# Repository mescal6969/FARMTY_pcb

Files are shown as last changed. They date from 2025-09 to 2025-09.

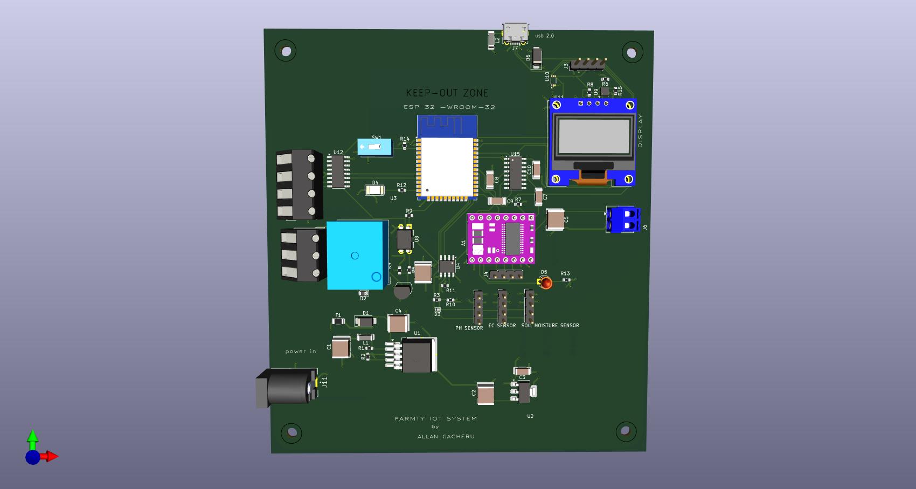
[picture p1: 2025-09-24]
farmty FULL.jpg

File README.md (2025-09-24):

 Farmty – IoT Smart Farming System

Farmty is an IoT-based smart farming system designed to monitor and control farm parameters in real time.  
This repository contains the KiCad PCB design , schematics , and related files for the Farmty hardware.

##  Features
- ESP32-WROOM-32 microcontroller (with WiFi + Bluetooth)
- RS485 sensor support:
  - Soil moisture
  - pH sensor
  - EC (Electrical Conductivity)
  - Temperature
- BME280 (humidity, pressure, temperature sensor)
- Load cell integration (for smart weighing)
- OLED (SSD1306) display
- Stepper motor driver
- Relay control for automation
- PC817 optocoupler isolation
- USB-to-UART via CH340C
- Modular power supply and terminal blocks

---

##  Software
- **Firmware:** ESP-IDF / Arduino framework
- **Programming language:** Python (for data processing) + C++ (for microcontroller)
- **IoT Dashboard:** Cloud-ready, customizable with MQTT/HTTP

---

##  Hardware
- Designed in KiCad
- Includes hierarchical schematics for modularity
- PCB fabrication-ready

##  How to Use
1. Clone this repo:
   ```bash
   https://github.com/mescal6969/FARMTY_pcb
2. Open the project in KiCad.
3. Modify schematics/PCB as needed.
4. Generate Gerber files for manufacturing.
5.Flash ESP32 with firmware to connect to IoT dashboard.

## IoT Integration

Farmty uses the **ESP32 WiFi module** to connect to the cloud.  
It can be integrated with:  
- **Blynk**  
- **ThingsBoard**  
- **Node-RED**  
- **MQTT brokers** (Mosquitto, HiveMQ)  

## License

This project is open-source under the **MIT License**.  
Feel free to use, modify, and share with attribution.

 Author
Allan Ng’ang’a Gacheru
BSc Mechatronics Engineering
Dedan Kimathi University of Technology

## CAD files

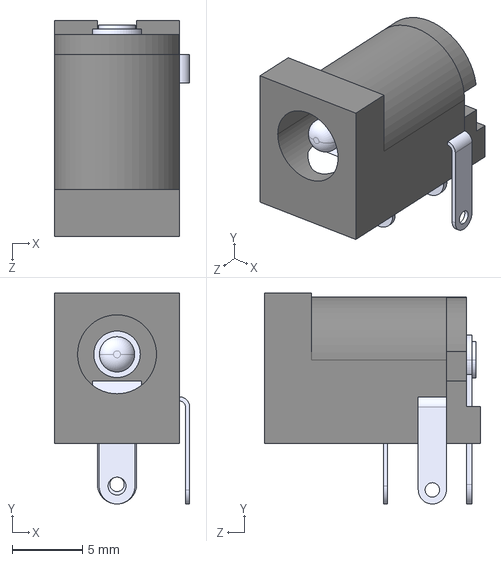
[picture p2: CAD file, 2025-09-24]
EJ508B.step
9.60 x 15.0 x 15.4 mm

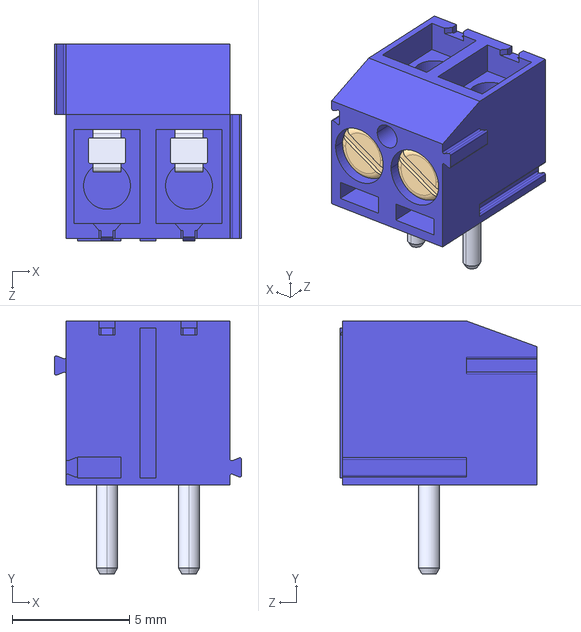
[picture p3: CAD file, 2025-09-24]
OSTTF020161--3DModel-STEP-56544.STEP
8.00 x 10.8 x 8.40 mm

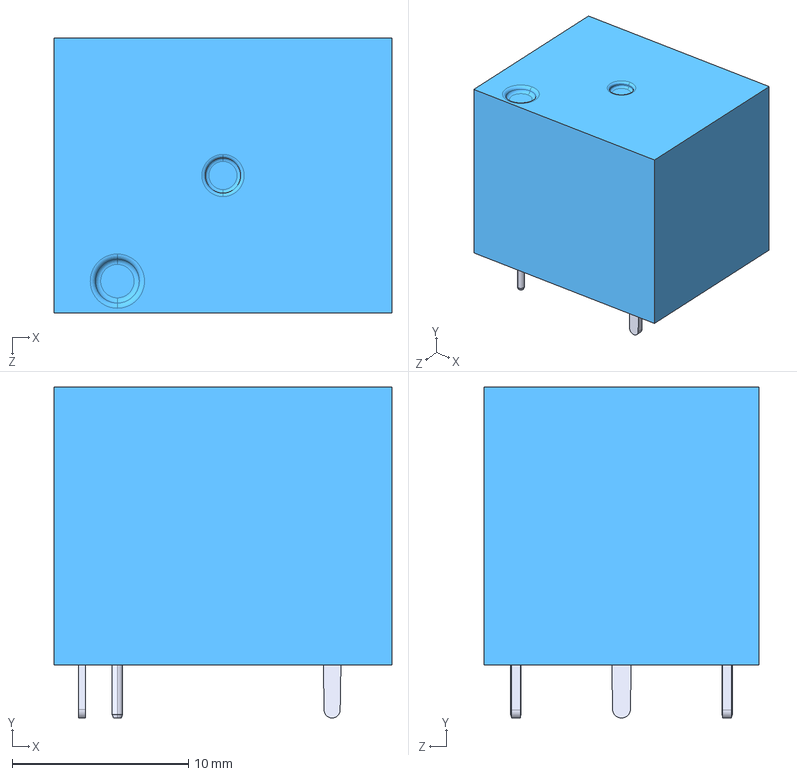
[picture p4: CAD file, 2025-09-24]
SRD-12VDC-SL-C.STEP
19.2 x 18.8 x 15.6 mm

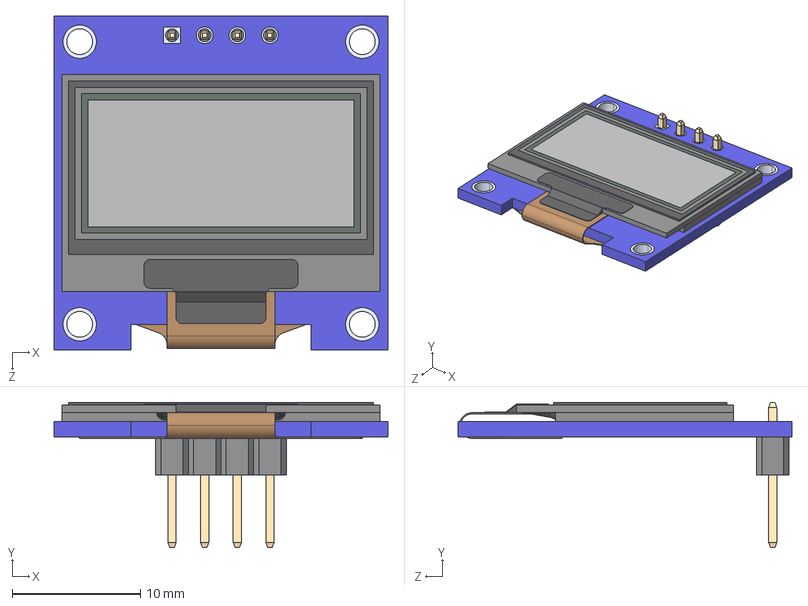
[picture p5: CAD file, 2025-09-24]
DM-OLED096-636--3DModel-STEP-56544.STEP
26.0 x 11.3 x 26.0 mm
DM-OLED096-636_Module
DM-OLED096-636_Panel

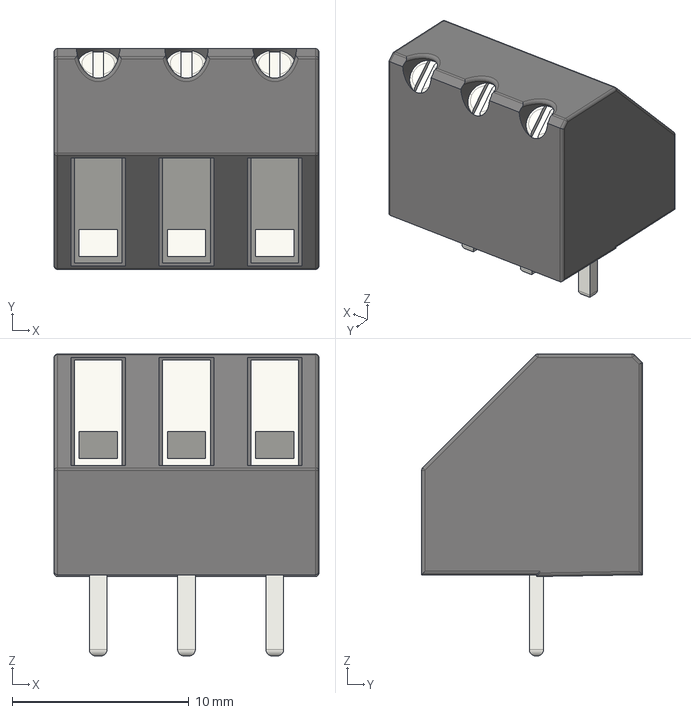
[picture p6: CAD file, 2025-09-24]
Altech_AK300_1x03_P5.00mm_45-Degree.step
15.0 x 12.5 x 17.1 mm

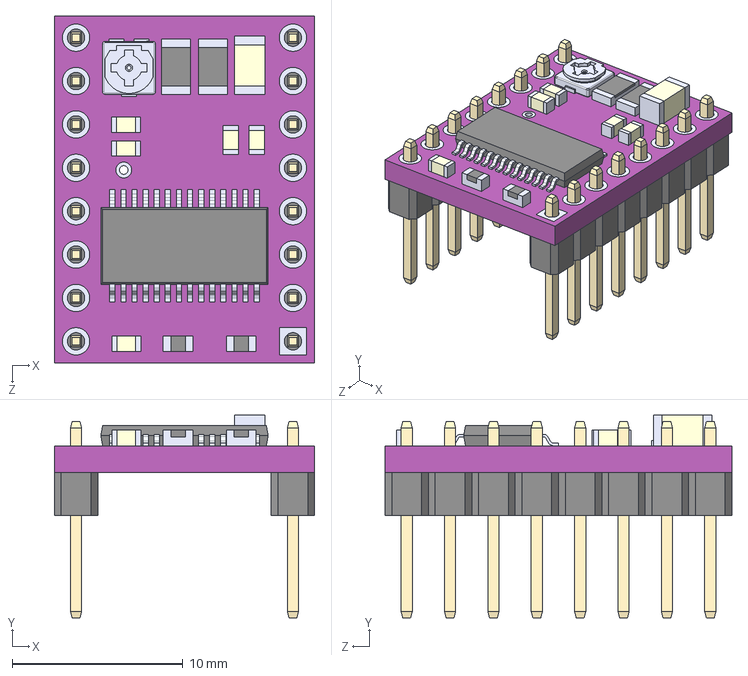
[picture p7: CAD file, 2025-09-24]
DRV8825 STEPPER MOTOR DRIVER CARRIER--3DModel-STEP-1.STEP
15.2 x 11.9 x 20.3 mm

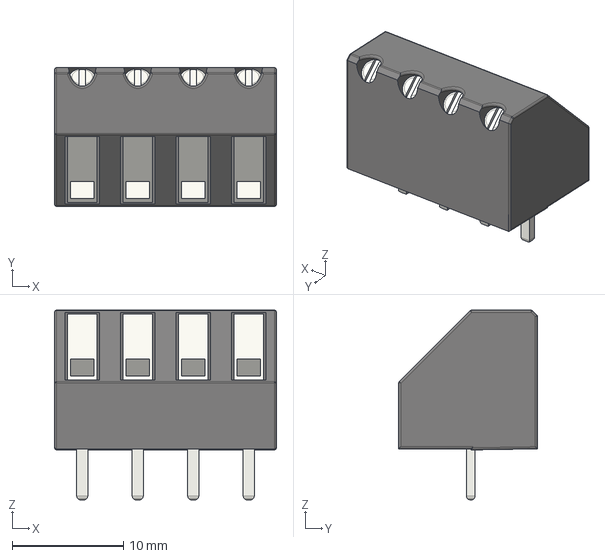
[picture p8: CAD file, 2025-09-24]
Altech_AK300_1x04_P5.00mm_45-Degree.step
20.0 x 12.5 x 17.1 mm

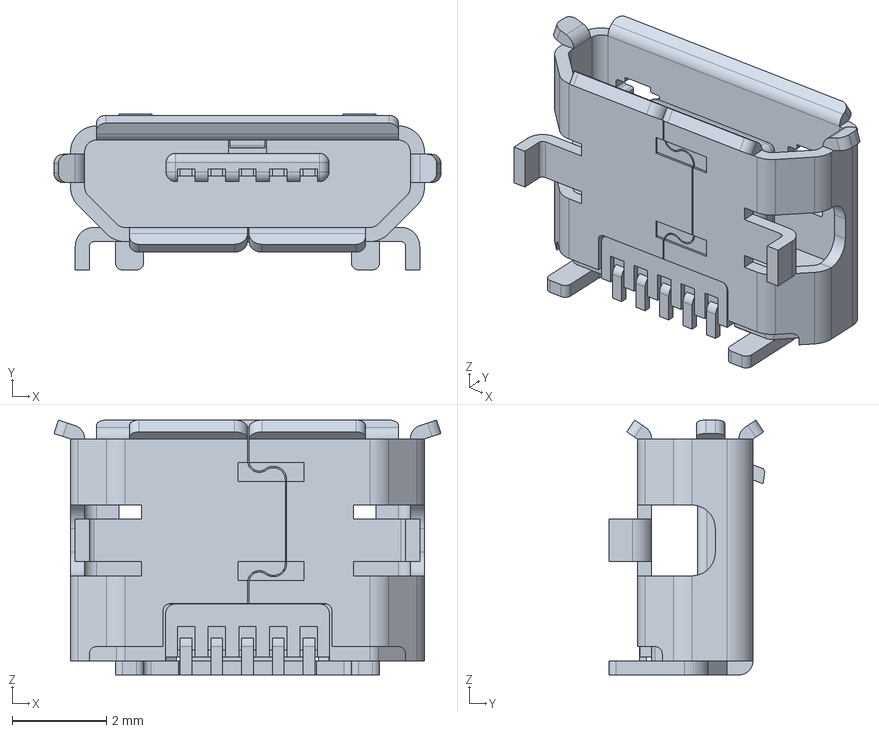
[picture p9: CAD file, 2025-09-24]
1050170001.stp
8.20 x 3.30 x 5.40 mm

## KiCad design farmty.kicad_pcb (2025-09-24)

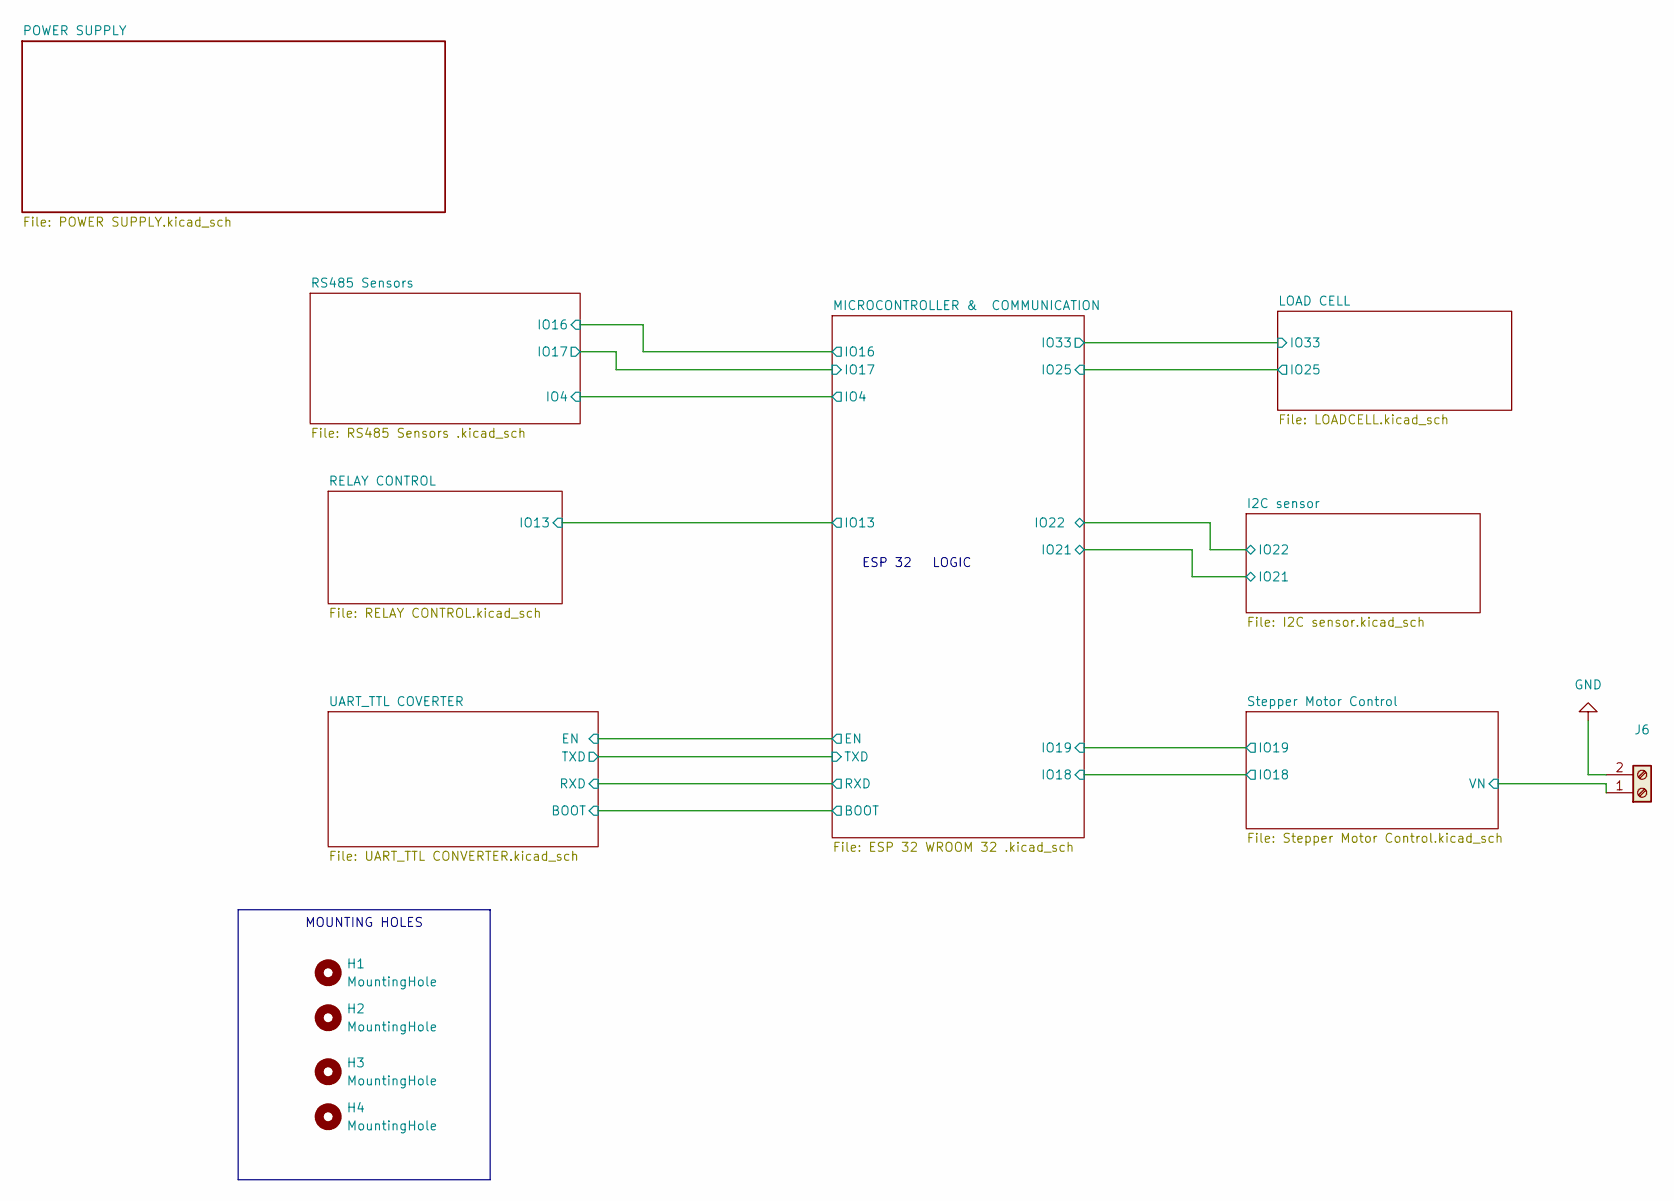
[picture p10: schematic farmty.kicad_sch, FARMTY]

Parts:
H1, H2, H3, H4: MountingHole; MountingHole_3.2mm_M3
J6: TerminalBlock_4Ucon_1x02_P3.50mm_Vertical

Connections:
/Stepper Motor Control/VN: J6.1; also elsewhere on the board
GND: J6.2; also elsewhere on the board

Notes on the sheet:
MOUNTING HOLES
ESP 32 LOGIC

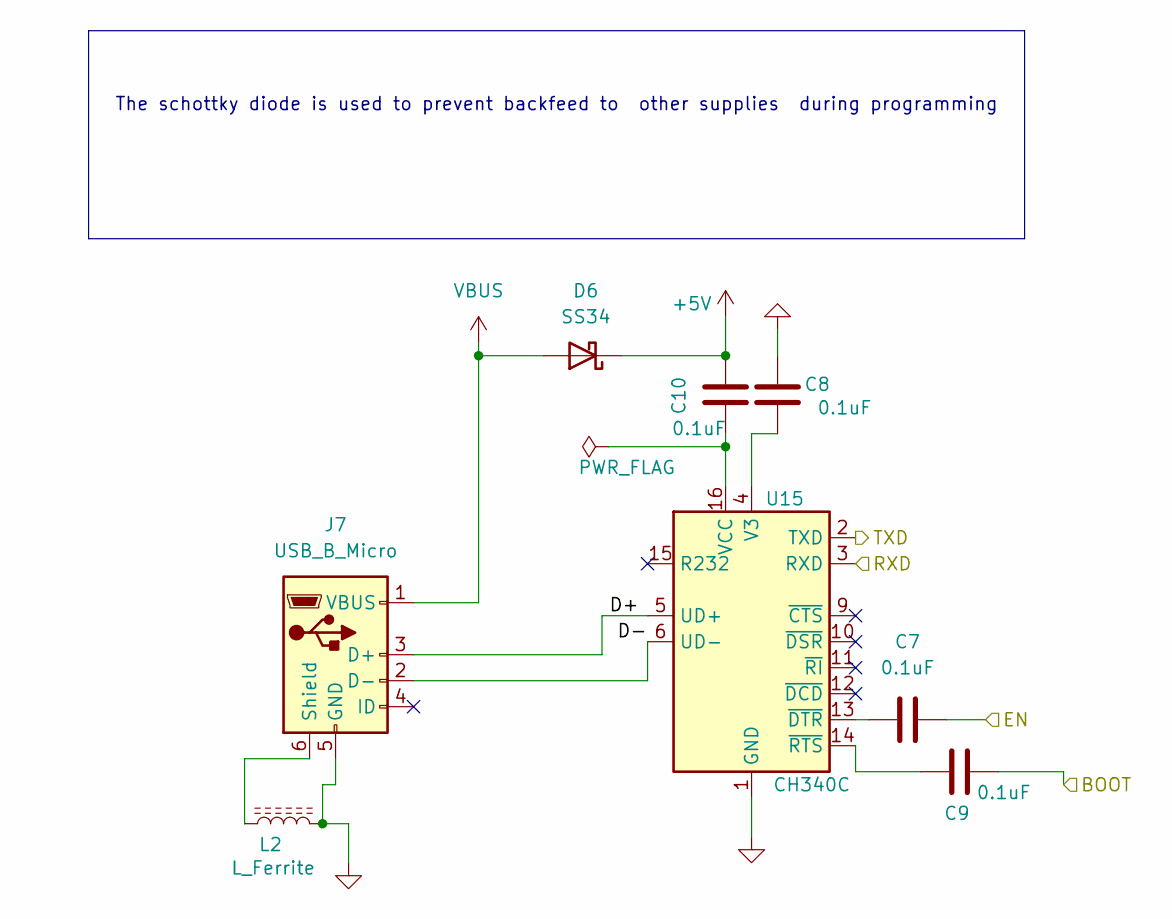
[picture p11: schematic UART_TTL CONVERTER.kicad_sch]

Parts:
C7, C8, C9, C10: 0.1uF; C_1808_4520Metric
D6: SS34; D_SMA
J7: USB_B_Micro; USB_Micro-B_Molex-105017-0001
L2: L_Ferrite; L_1806_4516Metric
U15: CH340C; SOIC-16_3.9x9.9mm_P1.27mm

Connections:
+5V: C10.1, D6.1 (K); also elsewhere on the board
/MICROCONTROLLER & COMMUNICATION/BOOT: C9.2; also elsewhere on the board
/MICROCONTROLLER & COMMUNICATION/EN: C7.2; also elsewhere on the board
/MICROCONTROLLER & COMMUNICATION/RXD: U15.3 (RXD); also elsewhere on the board
/MICROCONTROLLER & COMMUNICATION/TXD: U15.2 (TXD); also elsewhere on the board
GND: C8.1, J7.5 (GND), L2.2, U15.1 (GND); also elsewhere on the board
unnamed: J7.3 (D+), U15.5 (UD+)
unnamed: J7.2 (D-), U15.6 (UD-)
unnamed: J7.6 (Shield), L2.1
unnamed: C8.2, U15.4 (V3)
unnamed: C10.2, U15.16 (VCC)
unnamed: C7.1, U15.13 (~DTR)
unnamed: C9.1, U15.14 (~RTS)
VBUS: D6.2 (A), J7.1 (VBUS)

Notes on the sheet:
The schottky diode is used to prevent backfeed to other supplies during programming

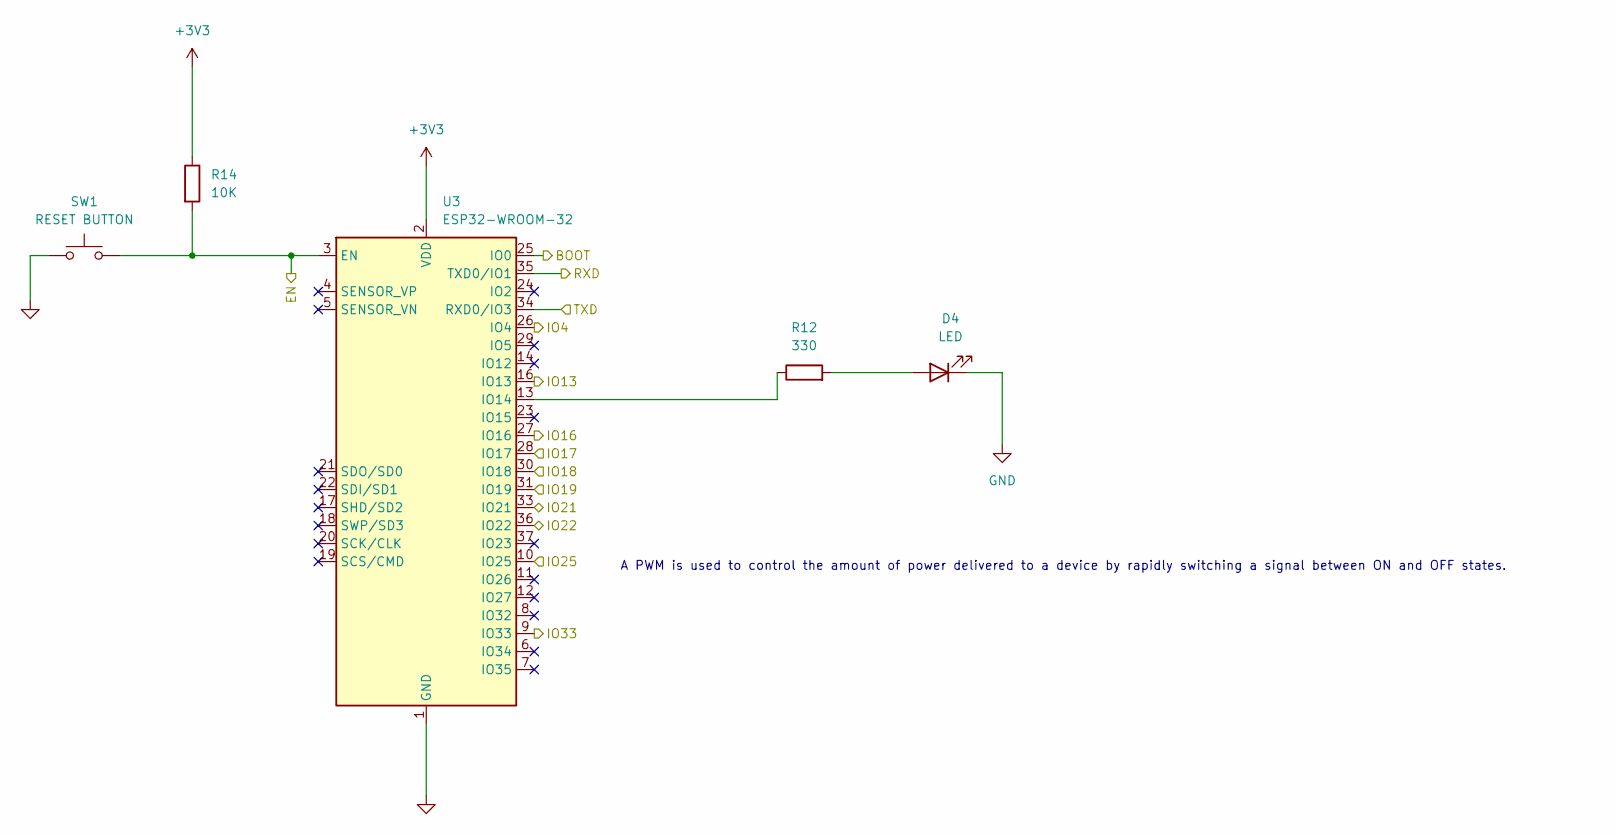
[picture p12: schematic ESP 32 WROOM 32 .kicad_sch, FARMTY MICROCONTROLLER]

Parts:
D4: LED; LED_2010_5025Metric
R12: 330; R_0603_1608Metric
R14: 10K; R_0603_1608Metric
SW1: RESET BUTTON; SW_DIP_SPSTx01_Slide_9.78x4.72mm_W7.62mm_P2.54mm
U3: ESP32-WROOM-32

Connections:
+3V3: R14.1, U3.2 (VDD); also elsewhere on the board
/I2C sensor/IO21: U3.33 (IO21); also elsewhere on the board
/I2C sensor/IO22: U3.36 (IO22); also elsewhere on the board
/LOAD CELL/IO25: U3.10 (IO25); also elsewhere on the board
/LOAD CELL/IO33: U3.9 (IO33); also elsewhere on the board
/MICROCONTROLLER & COMMUNICATION/BOOT: U3.25 (IO0); also elsewhere on the board
/MICROCONTROLLER & COMMUNICATION/EN: R14.2, SW1.2, U3.3 (EN); also elsewhere on the board
/MICROCONTROLLER & COMMUNICATION/IO4: U3.26 (IO4); also elsewhere on the board
/MICROCONTROLLER & COMMUNICATION/IO13: U3.16 (IO13); also elsewhere on the board
/MICROCONTROLLER & COMMUNICATION/IO16: U3.27 (IO16); also elsewhere on the board
/MICROCONTROLLER & COMMUNICATION/IO17: U3.28 (IO17); also elsewhere on the board
/MICROCONTROLLER & COMMUNICATION/IO18: U3.30 (IO18); also elsewhere on the board
/MICROCONTROLLER & COMMUNICATION/IO19: U3.31 (IO19); also elsewhere on the board
/MICROCONTROLLER & COMMUNICATION/RXD: U3.35 (TXD0/IO1); also elsewhere on the board
/MICROCONTROLLER & COMMUNICATION/TXD: U3.34 (RXD0/IO3); also elsewhere on the board
GND: D4.1 (K), SW1.1, U3.1 (GND), U3.15 (GND), U3.38 (GND), U3.39 (GND); also elsewhere on the board
unnamed: D4.2 (A), R12.2
unnamed: R12.1, U3.13 (IO14)

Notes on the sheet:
A PWM is used to control the amount of power delivered to a device by rapidly switching a signal between ON and OFF states.

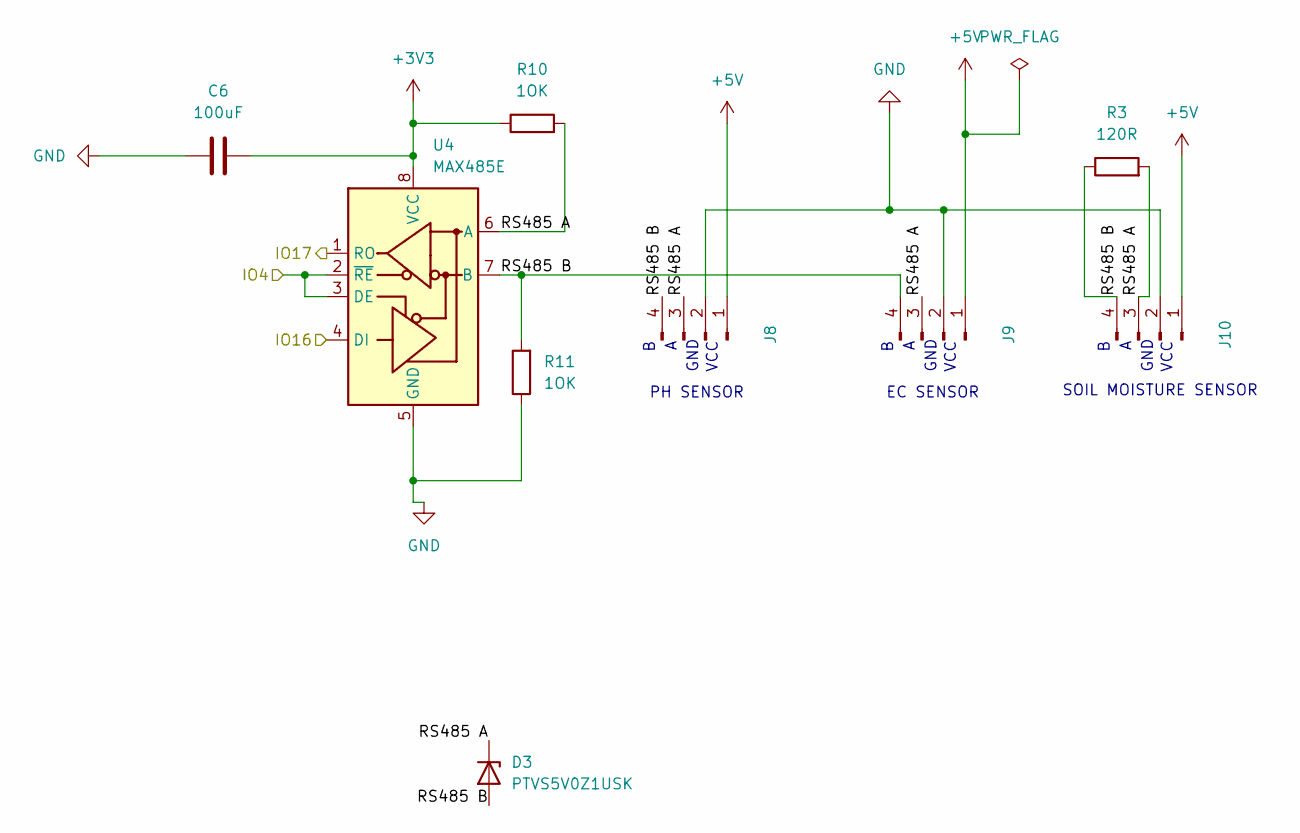
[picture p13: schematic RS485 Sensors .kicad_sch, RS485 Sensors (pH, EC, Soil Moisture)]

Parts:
C6: 100uF; C_2220_5750Metric
D3: PTVS5V0Z1USK; Nexperia_DSN1608-2_1.6x0.8mm
J8, J9, J10: Conn_01x04_Pin; PinHeader_1x04_P2.54mm_Vertical
R3: 120R; R_0603_1608Metric
R10, R11: 1OK; R_0603_1608Metric
U4: MAX485E; SOIC-8_3.9x4.9mm_P1.27mm

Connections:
+3V3: C6.2, R10.1, U4.8 (VCC); also elsewhere on the board
+5V: J8.1, J9.1, J10.1; also elsewhere on the board
/MICROCONTROLLER & COMMUNICATION/IO4: U4.2 (~RE), U4.3 (DE); also elsewhere on the board
/MICROCONTROLLER & COMMUNICATION/IO16: U4.4 (DI); also elsewhere on the board
/MICROCONTROLLER & COMMUNICATION/IO17: U4.1 (RO); also elsewhere on the board
/RS485 Sensors/RS485 A: D3.1 (K), J8.3, J9.3, J10.3, R3.2, R10.2, U4.6 (A)
/RS485 Sensors/RS485 B: D3.2 (A), J8.4, J9.4, J10.4, R3.1, R11.2, U4.7 (B)
GND: C6.1, J8.2, J9.2, J10.2, R11.1, U4.5 (GND); also elsewhere on the board

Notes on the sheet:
VCC
EC SENSOR
GND
PH SENSOR
SOIL MOISTURE SENSOR

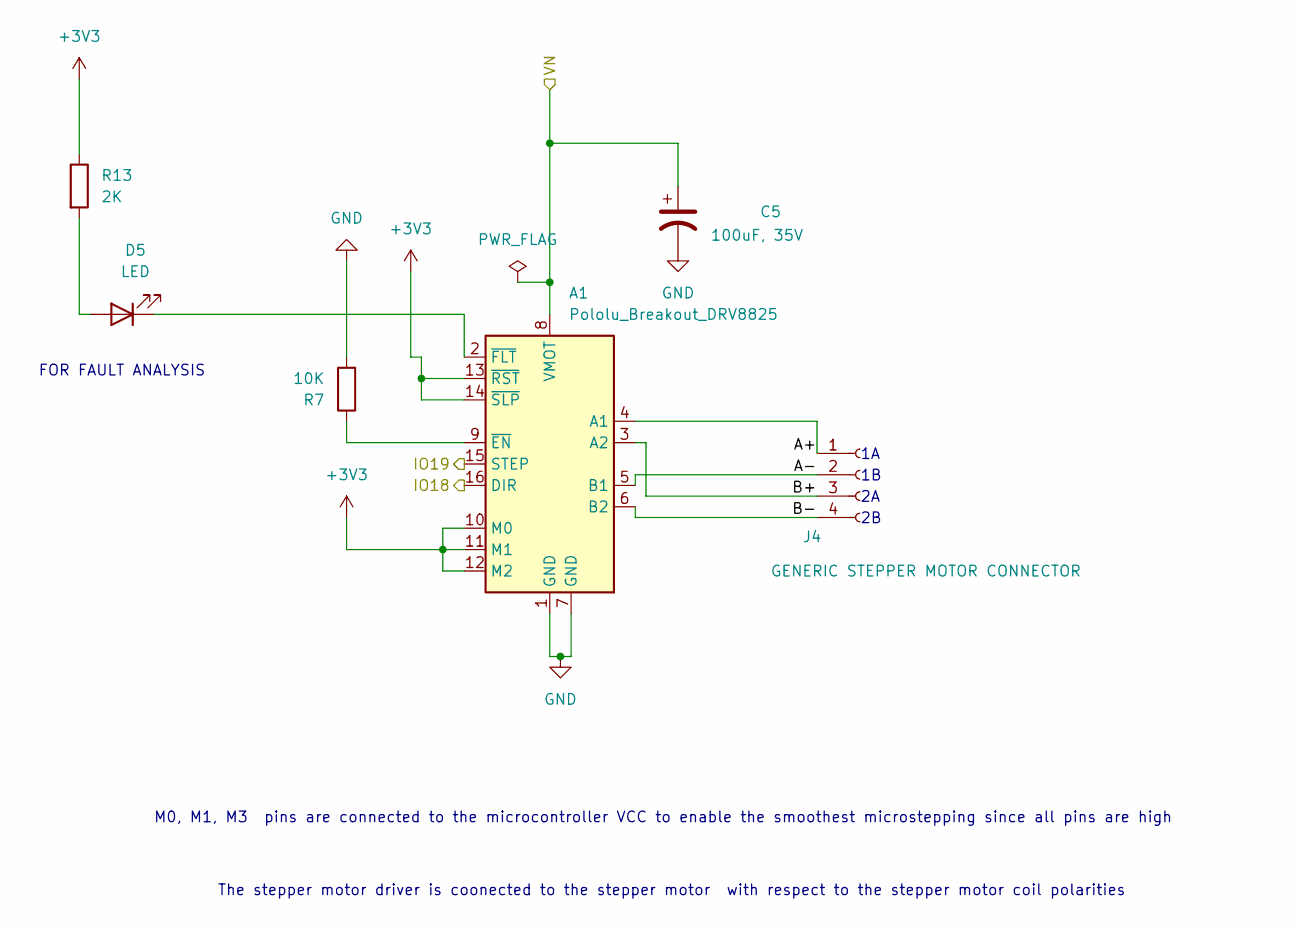
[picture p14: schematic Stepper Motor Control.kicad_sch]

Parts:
A1: Pololu_Breakout_DRV8825; Pololu_Breakout-16_15.2x20.3mm
C5: 100uF, 35V; C_2220_5750Metric
D5: LED; LED_D3.0mm
J4: GENERIC STEPPER MOTOR CONNECTOR; PinHeader_1x04_P2.54mm_Vertical
R7: 10K; R_0603_1608Metric
R13: 2K; R_0603_1608Metric

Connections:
+3V3: A1.10 (M0), A1.11 (M1), A1.12 (M2), A1.13 (~RST), A1.14 (~SLP), R13.1; also elsewhere on the board
/MICROCONTROLLER & COMMUNICATION/IO18: A1.16 (DIR); also elsewhere on the board
/MICROCONTROLLER & COMMUNICATION/IO19: A1.15 (STEP); also elsewhere on the board
/Stepper Motor Control/A+: A1.4 (A1), J4.1
/Stepper Motor Control/A-: A1.5 (B1), J4.2
/Stepper Motor Control/B+: A1.3 (A2), J4.3
/Stepper Motor Control/B-: A1.6 (B2), J4.4
/Stepper Motor Control/VN: A1.8 (VMOT), C5.1; also elsewhere on the board
GND: A1.1 (GND), A1.7 (GND), C5.2, R7.2; also elsewhere on the board
unnamed: A1.9 (~EN), R7.1
unnamed: A1.2 (~FLT), D5.1 (K)
unnamed: D5.2 (A), R13.2

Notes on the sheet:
M0, M1, M3 pins are connected to the microcontroller VCC to enable the smoothest microstepping since all pins are high
The stepper motor driver is coonected to the stepper motor with respect to the stepper motor coil polarities
FOR FAULT ANALYSIS

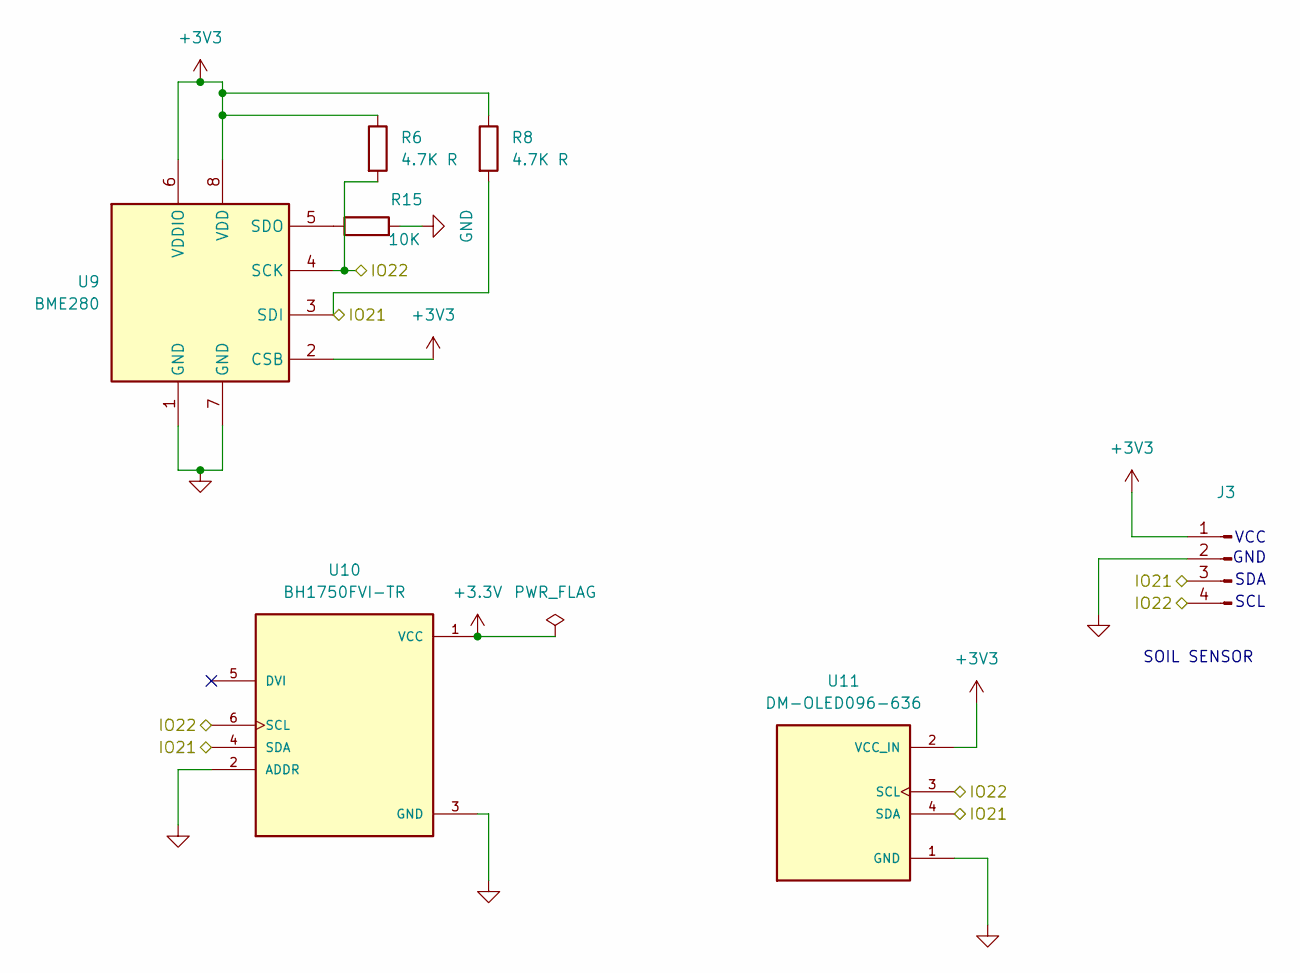
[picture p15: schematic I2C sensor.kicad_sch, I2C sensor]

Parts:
J3: Conn_01x04_Pin; PinHeader_1x04_P2.54mm_Vertical
R6, R8: 4.7K R; R_0603_1608Metric
R15: 10K; R_0603_1608Metric
U9: BME280; Bosch_LGA-8_2.5x2.5mm_P0.65mm_ClockwisePinNumbering
U10: BH1750FVI-TR; XDCR_BH1750FVI-TR; PARTREV D
U11: DM-OLED096-636; MODULE_DM-OLED096-636; PARTREV 2018-09-10

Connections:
+3.3V: U10.1 (VCC)
+3V3: J3.1, R6.1, R8.1, U9.2 (CSB), U9.6 (VDDIO), U9.8 (VDD), U11.2 (VCC_IN); also elsewhere on the board
/I2C sensor/IO21: J3.3, R8.2, U9.3 (SDI), U10.4 (SDA), U11.4 (SDA); also elsewhere on the board
/I2C sensor/IO22: J3.4, R6.2, U9.4 (SCK), U10.6 (SCL), U11.3 (SCL); also elsewhere on the board
GND: J3.2, R15.2, U9.1 (GND), U9.7 (GND), U10.2 (ADDR), U10.3 (GND), U11.1 (GND); also elsewhere on the board
unnamed: R15.1, U9.5 (SDO)

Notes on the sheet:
VCC
SCL
SOIL SENSOR
SDA
GND

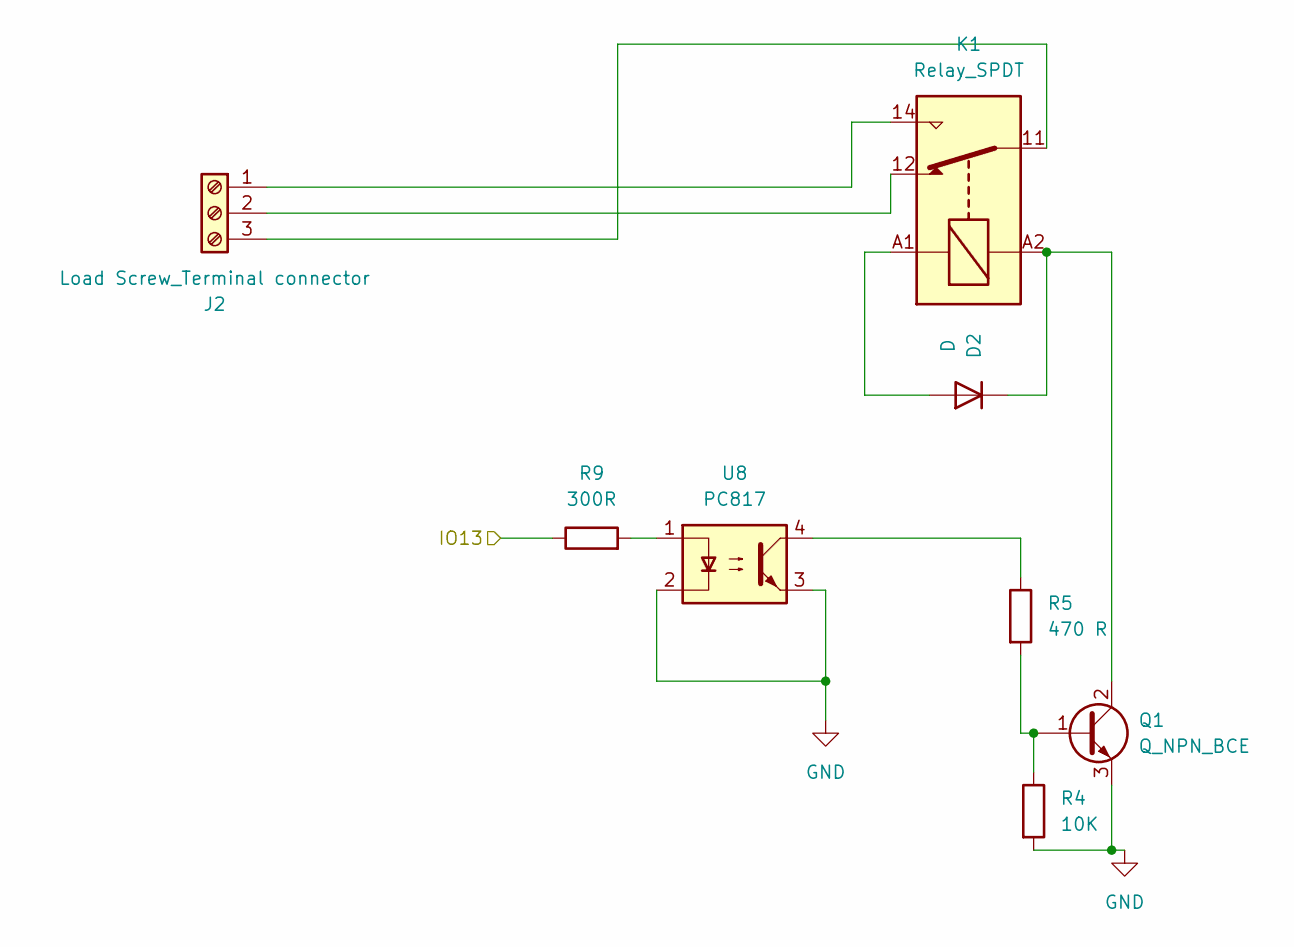
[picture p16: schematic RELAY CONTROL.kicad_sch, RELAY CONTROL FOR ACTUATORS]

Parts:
D2: D; D_0805_2012Metric
J2: Load Screw_Terminal connector; Altech_AK100_1x03_P5.00mm
K1: Relay_SPDT; Relay_SPDT_Hongfa_JQC-3FF_0XX-1Z
Q1: Q_NPN_BCE; TO-92_Inline
R4: 10K; R_0603_1608Metric
R5: 470 R; R_0603_1608Metric
R9: 300R; R_0603_1608Metric
U8: PC817; DIP-4_W7.62mm

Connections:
/MICROCONTROLLER & COMMUNICATION/IO13: R9.1; also elsewhere on the board
GND: Q1.3 (E), R4.2, U8.2, U8.3; also elsewhere on the board
unnamed: D2.2 (A), K1.A1
unnamed: D2.1 (K), K1.A2, Q1.2 (C)
unnamed: J2.1, K1.14
unnamed: J2.2, K1.12
unnamed: J2.3, K1.11
unnamed: Q1.1 (B), R4.1, R5.2
unnamed: R5.1, U8.4
unnamed: R9.2, U8.1

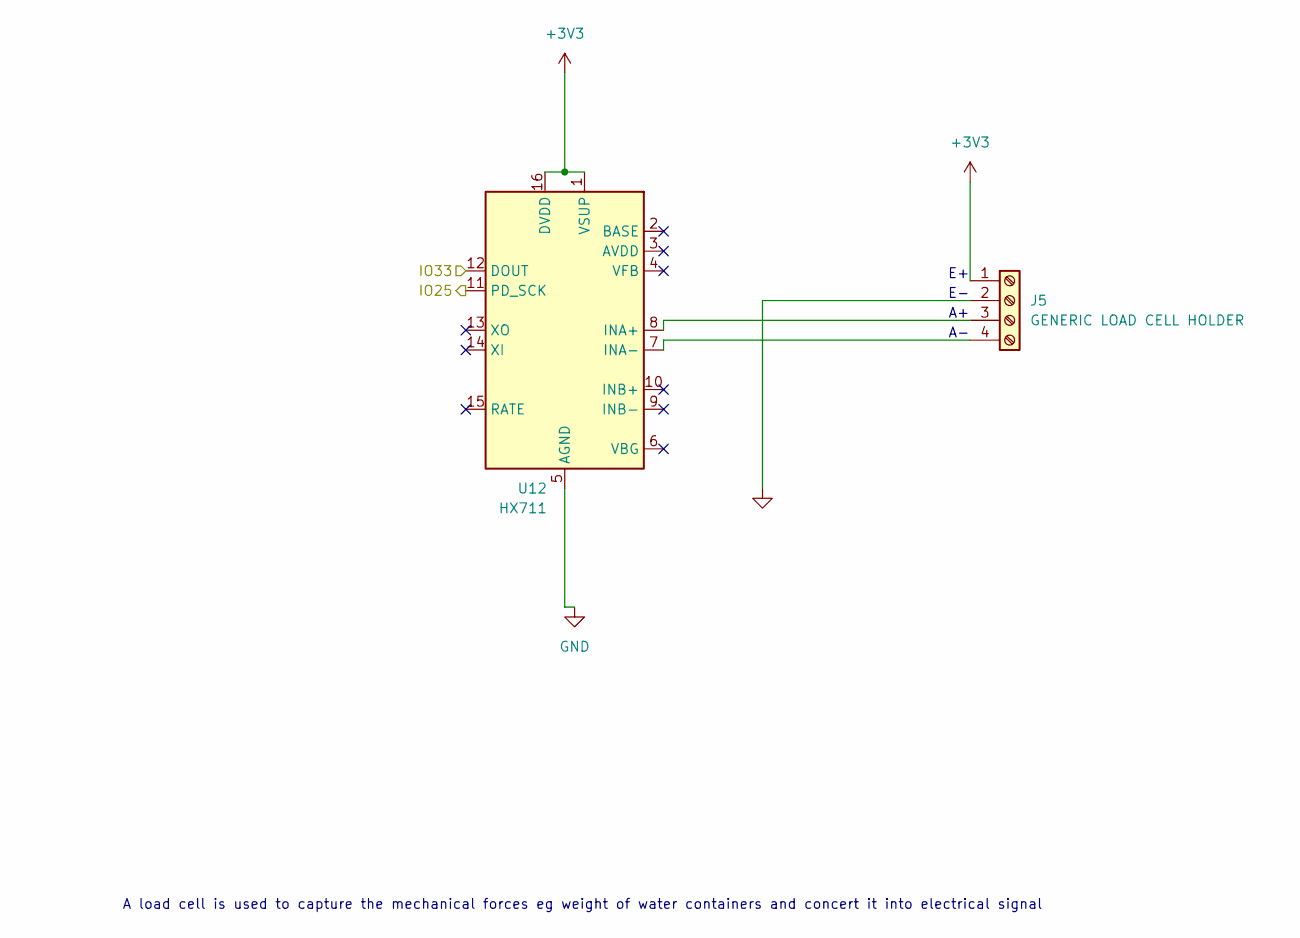
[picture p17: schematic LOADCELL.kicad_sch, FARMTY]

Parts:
J5: GENERIC LOAD CELL HOLDER; Altech_AK100_1x04_P5.00mm
U12: HX711; SOP-16_3.9x9.9mm_P1.27mm

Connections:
+3V3: J5.1, U12.1 (VSUP), U12.16 (DVDD); also elsewhere on the board
/LOAD CELL/IO25: U12.11 (PD_SCK); also elsewhere on the board
/LOAD CELL/IO33: U12.12 (DOUT); also elsewhere on the board
GND: J5.2, U12.5 (AGND); also elsewhere on the board
unnamed: J5.3, U12.8 (INA+)
unnamed: J5.4, U12.7 (INA-)

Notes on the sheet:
A load cell is used to capture the mechanical forces eg weight of water containers and concert it into electrical signal

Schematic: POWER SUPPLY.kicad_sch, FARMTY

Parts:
C1: 1000uF, 16V; C_2220_5750Metric
C2: 220uF, 10V; C_2220_5750Metric
C3: 100uF, 6.3V; C_1808_4520Metric
C4: 220uF, 25V; C_2220_5750Metric
D1: SS34; D_SMA
F1: 2.5A; Fuse_1206_3216Metric
J11: EJ508B; MPD_EJ508B; PARTREV G
L1: 33uH, 3A; L_1806_4516Metric
R1: 3.3k; R_0603_1608Metric
R2: 1k; R_0603_1608Metric
U1: LM2596S-5; TO-263-5_TabPin3
U2: AMS1117-3.3; SOT-223-3_TabPin2

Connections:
5V: C1.1, L1.2
+3V3: C3.1, U2.2 (VO); also elsewhere on the board
+12V: F1.1, J11.1
/POWER SUPPLY/+12Vin: D1.2 (A), F1.2
GND: C1.2, C2.2, C3.2, C4.2, J11.2, R2.2, U1.3 (GND), U2.1 (GND); also elsewhere on the board
unnamed: C4.1, D1.1 (K), U1.1 (VIN)
unnamed: R1.2, R2.1, U1.4 (FB)
unnamed: L1.1, R1.1, U1.2 (OUT)
unnamed: C2.1, U2.3 (VI)

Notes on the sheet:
POWER_SUPPLY

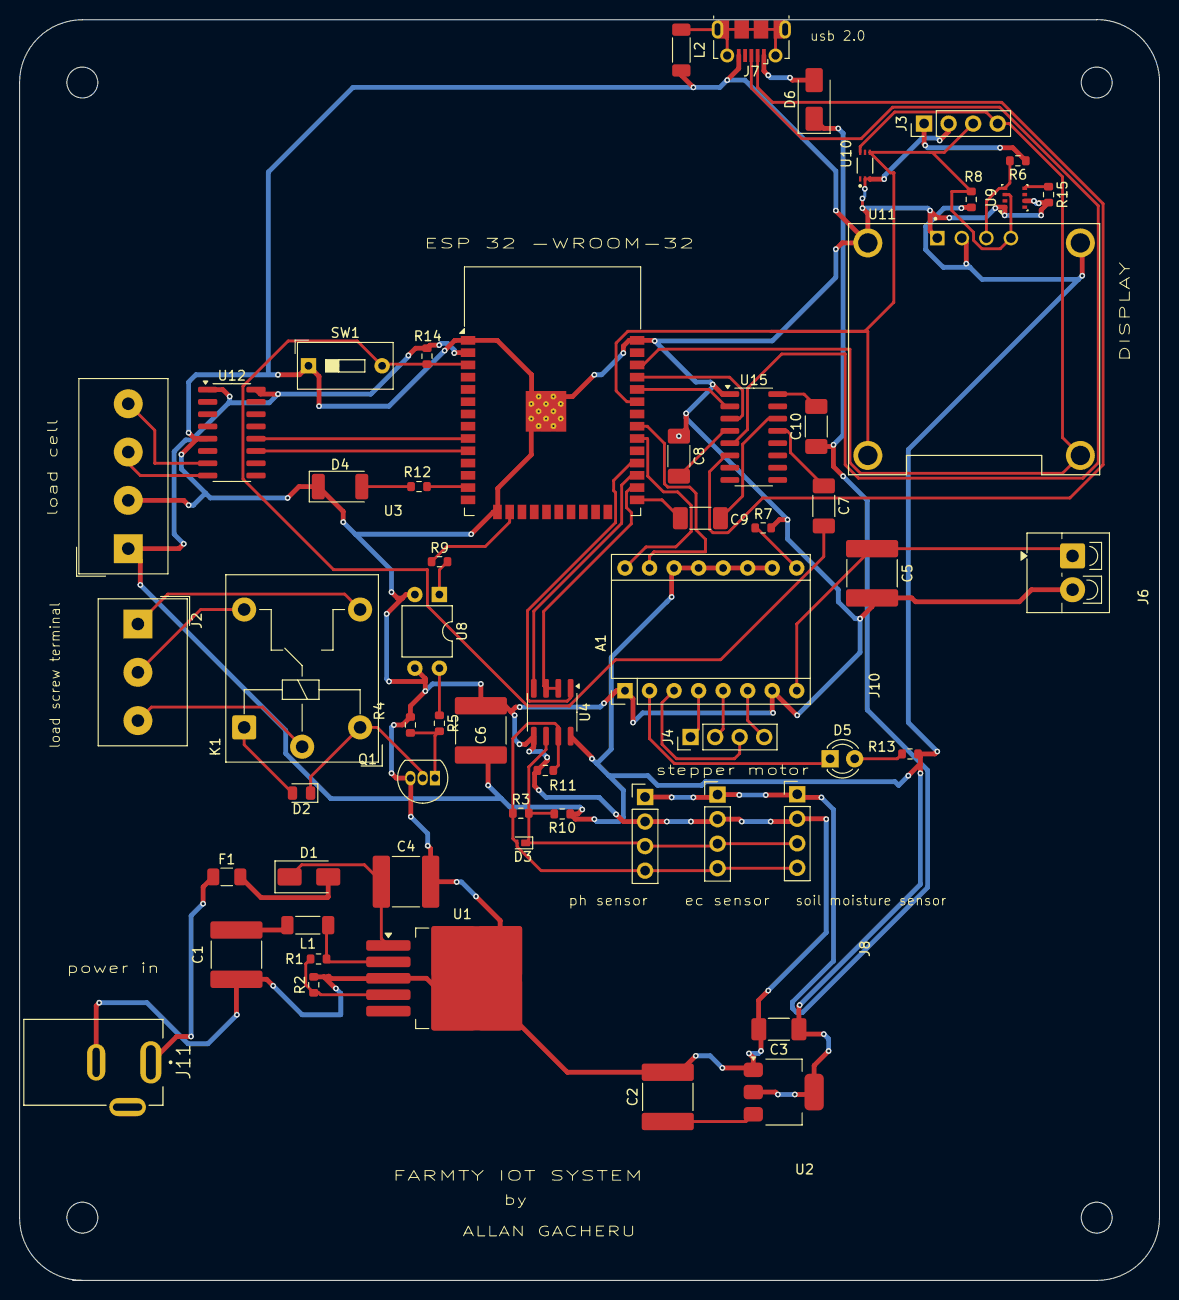
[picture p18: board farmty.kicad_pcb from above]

Board: 2 copper layers, 118.0 x 130.5 mm, 62 parts (0 on the bottom side), 55 nets.

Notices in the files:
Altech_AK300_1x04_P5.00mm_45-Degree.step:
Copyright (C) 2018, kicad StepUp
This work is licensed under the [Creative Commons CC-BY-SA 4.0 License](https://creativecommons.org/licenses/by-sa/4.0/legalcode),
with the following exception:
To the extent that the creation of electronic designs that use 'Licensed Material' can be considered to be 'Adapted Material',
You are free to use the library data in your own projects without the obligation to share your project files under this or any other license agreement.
